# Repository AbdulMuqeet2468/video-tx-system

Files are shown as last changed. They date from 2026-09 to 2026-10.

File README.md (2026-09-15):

# video-tx-system

Under progress...

## Trail 1
Planned to use TPS54560BQDDARQ1 IC from Texas Instruments; 50V input and 5V 6A output. 
- Footprint was too big
- Inductor (15uH 11A) had bigger footprint and not available

## Trail 2
Using LM76003RNPR with lesser eficiency and better footprint. 
- Completed simulation
- Created symbols and footprints for missing components
- completed schematic

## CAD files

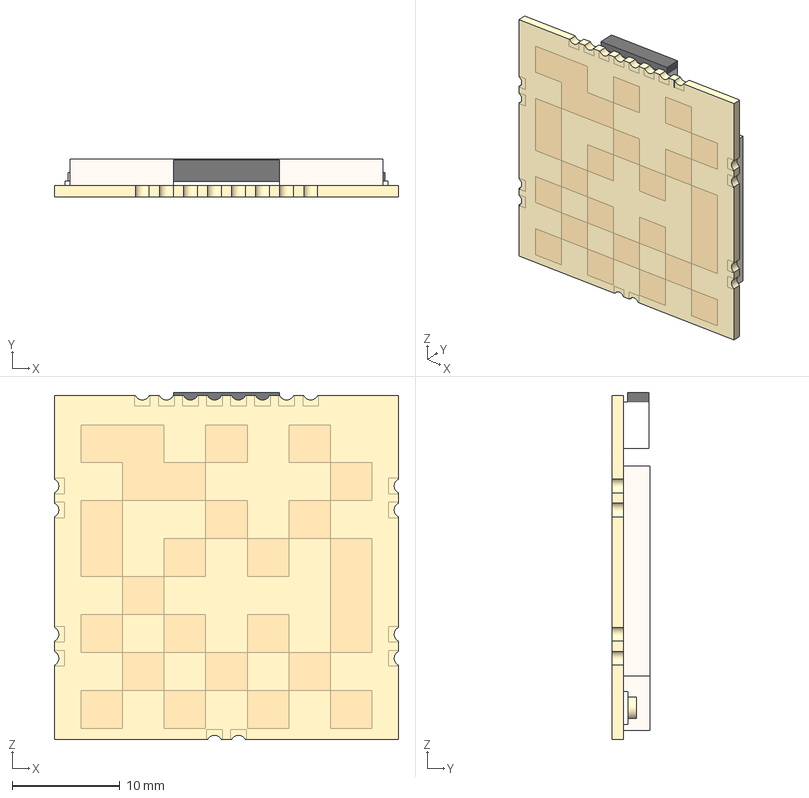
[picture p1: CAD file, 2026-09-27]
3D CAD Files/BL-M8812EU2 Long Range Wifi Module.stp
32.0 x 3.53 x 32.3 mm

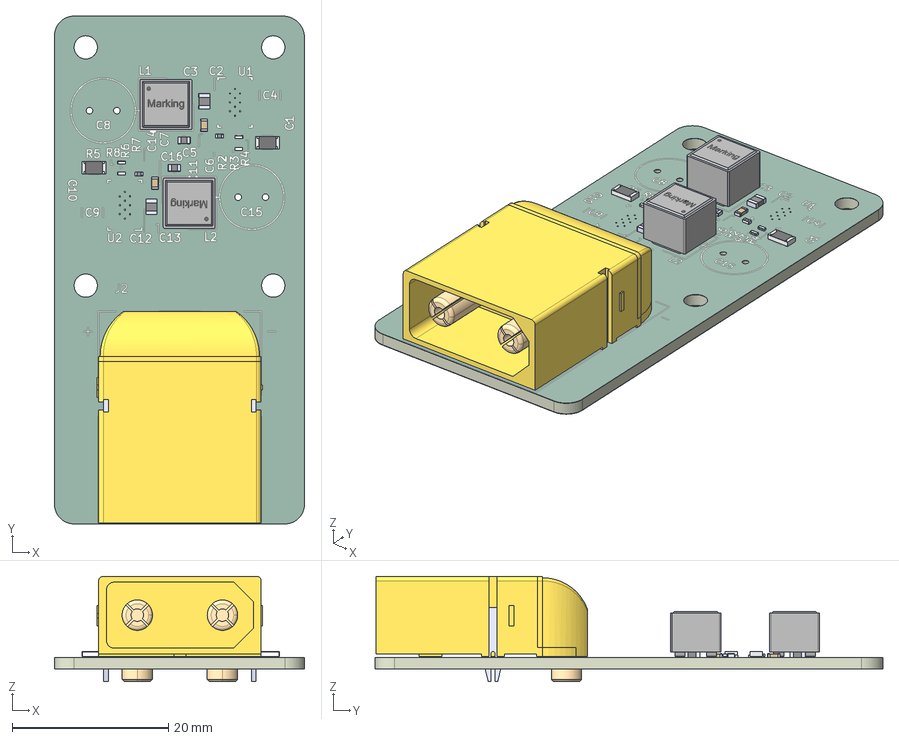
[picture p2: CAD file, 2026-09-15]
KiCAD Files/VTX.step
32.0 x 65.0 x 13.5 mm
RT1206BRD07120RL x 2
CC0603ZRY5V8BB105 x 2
AC0805KKX7R0BB104 x 2
RE0402FRE07100KL x 2
XT90PW-M
SR0402JR-7W10RL x 4
CL10A104KA8NNNC x 2
L_Wurth_WE-XHMI_6060 x 2
VTXED8C_silkscreen
VTXED8C_soldermask x 2
VTXED8C_PCB

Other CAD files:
3D CAD Files/BL-M8812EU2 Long Range Wifi Module.SLDPRT

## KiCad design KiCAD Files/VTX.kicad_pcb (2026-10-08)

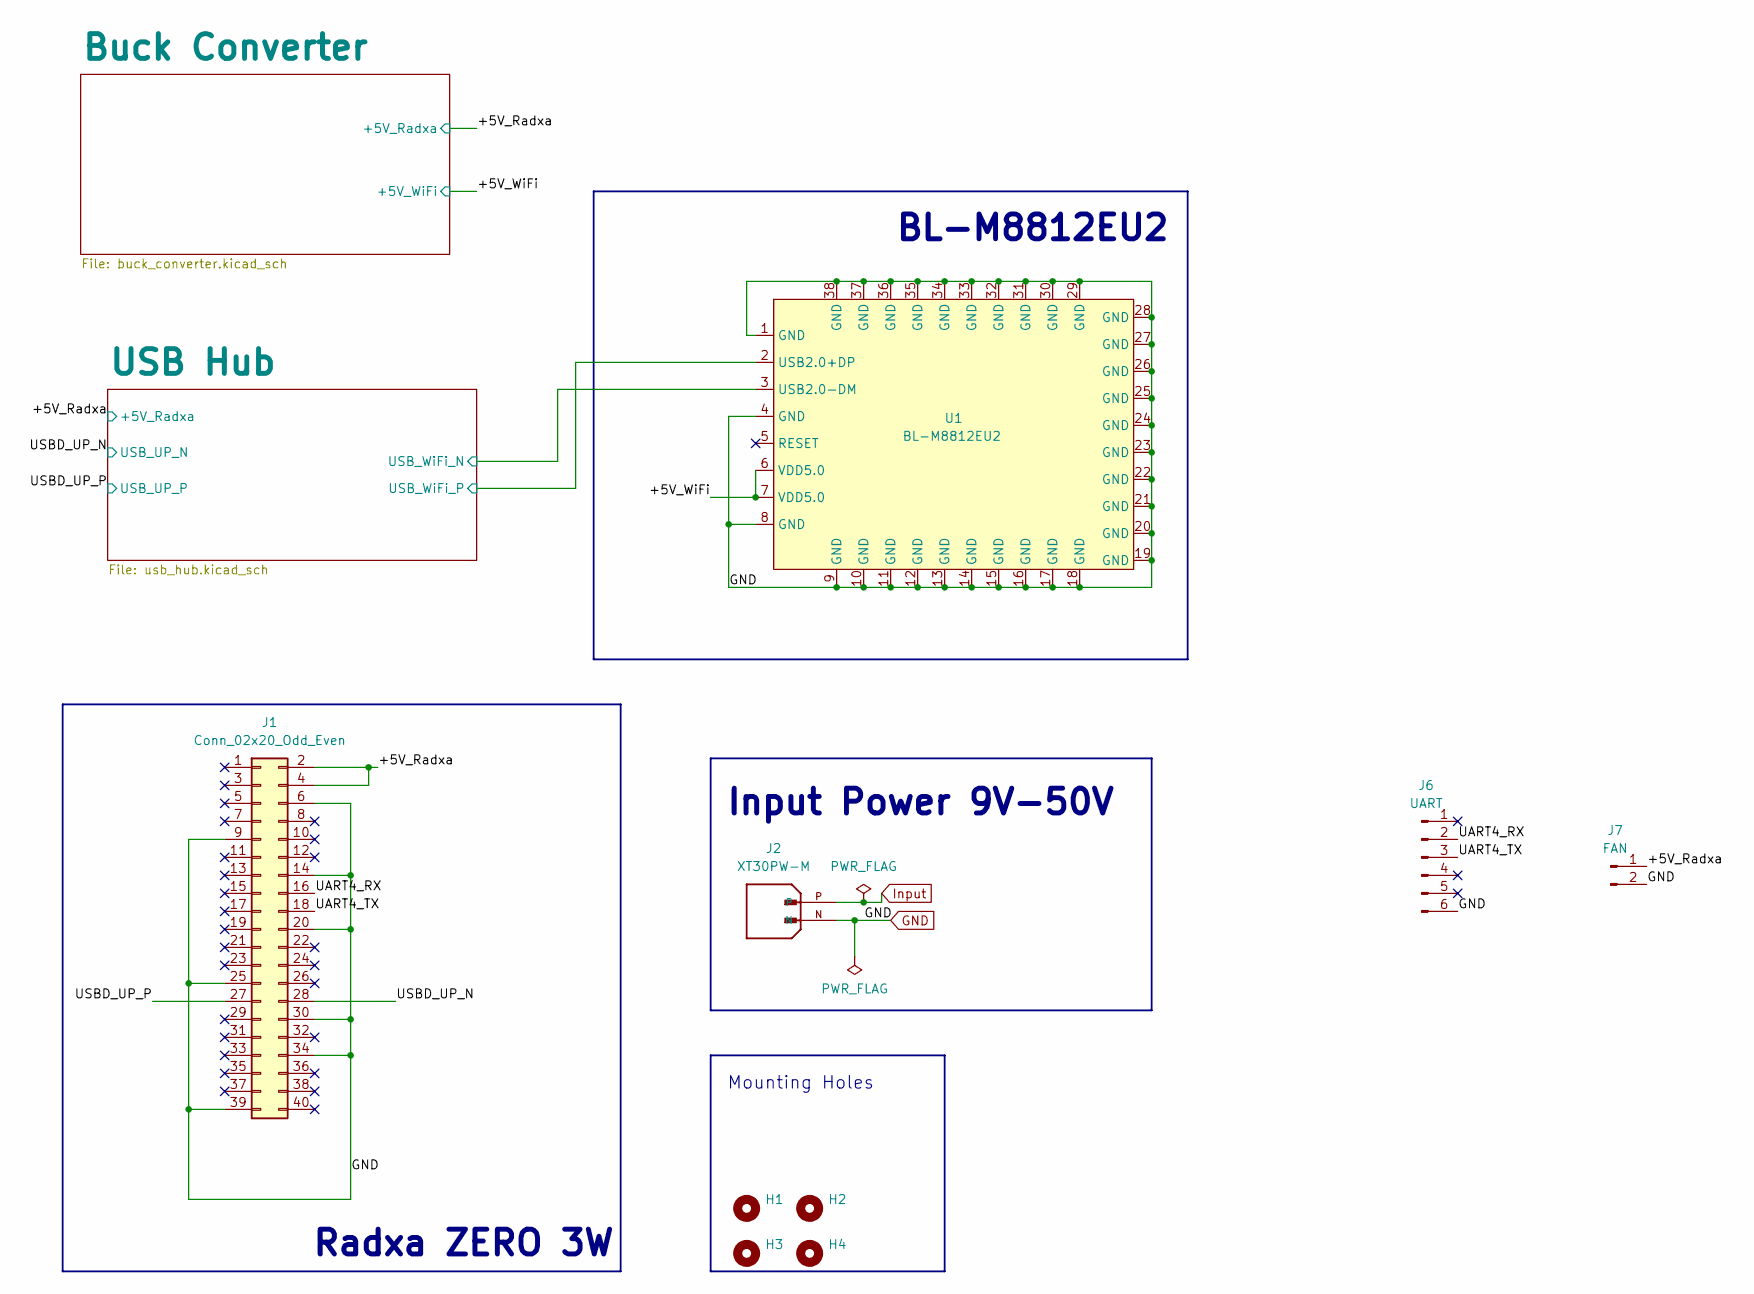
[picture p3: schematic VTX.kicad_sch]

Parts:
H1, H2, H3, H4: MountingHole; MountingHole_3mm
J1: Conn_02x20_Odd_Even; PinHeader_2x20_P2.54mm_Vertical
J2: XT30PW-M; AMASS_XT30PW-M; PARTREV 1.2
J6: UART; JST_GH_SM06B-GHS-TB_1x06-1MP_P1.25mm_Horizontal
J7: FAN; JST_GH_SM02B-GHS-TB_1x02-1MP_P1.25mm_Horizontal
U1: BL-M8812EU2

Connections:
+5V_Radxa: J1.2, J1.4, J7.1; also elsewhere on the board
+5V_WiFi: U1.6 (VDD5.0), U1.7 (VDD5.0); also elsewhere on the board
/UART4_RX: J1.16, J6.2
/UART4_TX: J1.18, J6.3
/USB Hub/USB_WiFi_N: U1.3 (USB2.0-DM); also elsewhere on the board
/USB Hub/USB_WiFi_P: U1.2 (USB2.0+DP); also elsewhere on the board
/USBD_UP_N: J1.28; also elsewhere on the board
/USBD_UP_P: J1.27; also elsewhere on the board
GND: J1.6, J1.9, J1.14, J1.20, J1.25, J1.30, J1.34, J1.39, J2.N, J6.6, J7.2, U1.1 (GND), U1.4 (GND), U1.8 (GND), U1.9 (GND), U1.10 (GND), U1.11 (GND), U1.12 (GND), U1.13 (GND), U1.14 (GND), U1.15 (GND), U1.16 (GND), U1.17 (GND), U1.18 (GND), U1.19 (GND), U1.20 (GND), U1.21 (GND), U1.22 (GND), U1.23 (GND), U1.24 (GND), U1.25 (GND), U1.26 (GND), U1.27 (GND), U1.28 (GND), U1.29 (GND), U1.30 (GND), U1.31 (GND), U1.32 (GND), U1.33 (GND), U1.34 (GND), U1.35 (GND), U1.36 (GND), U1.37 (GND), U1.38 (GND); also elsewhere on the board
Input: J2.P; also elsewhere on the board

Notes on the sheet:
BL-M8812EU2
Mounting Holes
Radxa ZERO 3W
Input Power 9V-50V

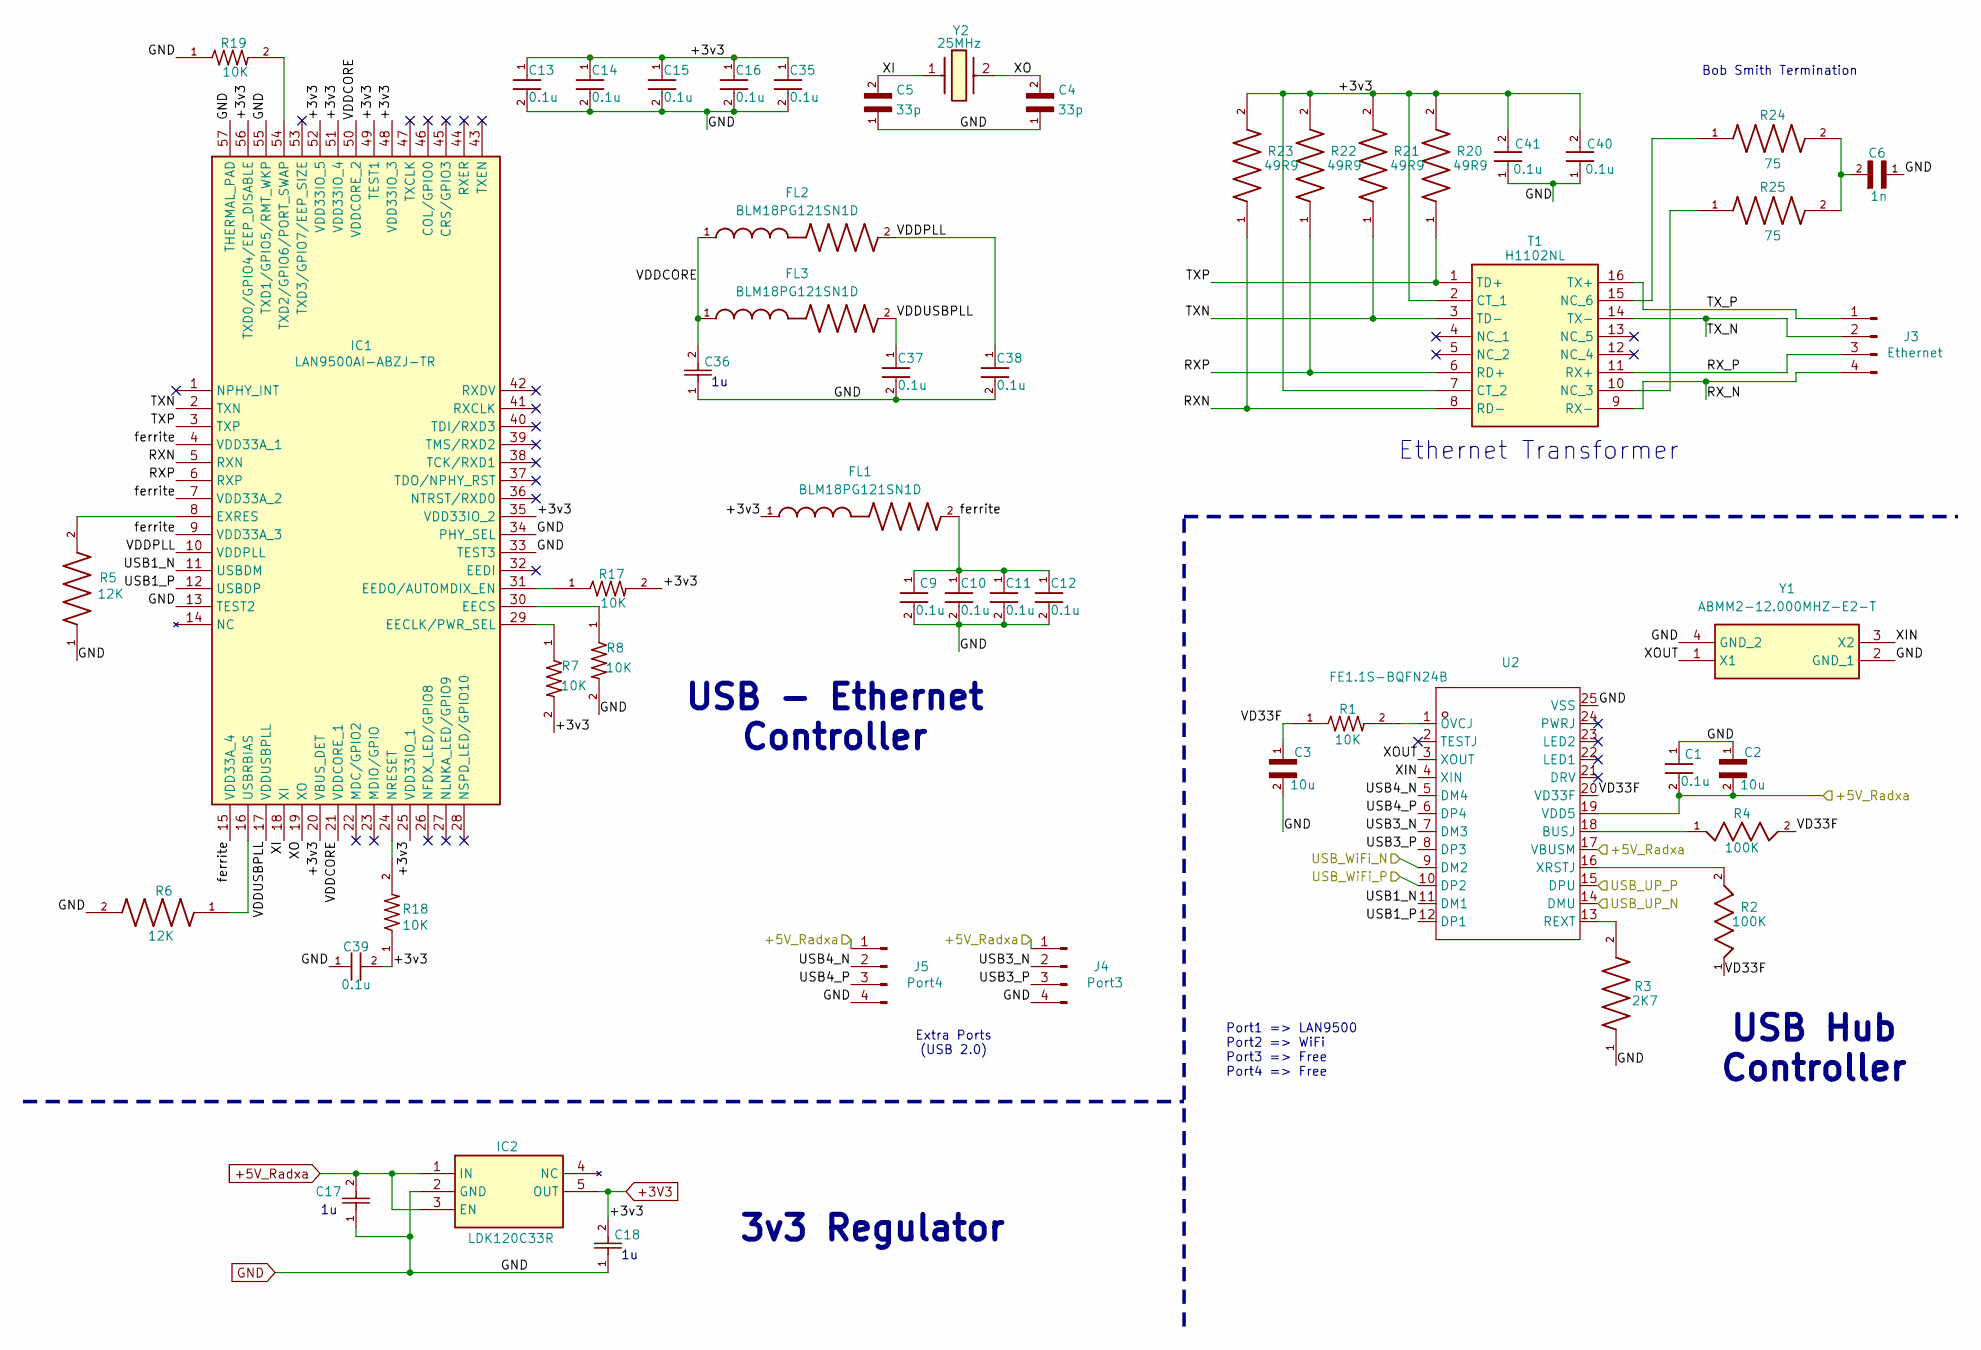
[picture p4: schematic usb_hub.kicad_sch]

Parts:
C1, C9, C10, C11, C12, C13, C14, C15, C16, C35, C37, C38, C39, C40, C41: 0.1u; 100nF0603
C2, C3: 10u; CL10A106KQ8NNNC
C4, C5: 33p; TCC0402COG330J500AT; PARTREV 2015-02-10
C6: 1n; C1206C102JGRACTU
C17, C18: 1uF; CC0805KKX7R6BB225; VOLTAGERATING 10V; TOLERANCE ±10%; MPN CC0805KKX7R6BB225
C36: 1uF; C0805X474K101T; VOLTAGERATING 10V; TOLERANCE ±10%; MPN CC0805KKX7R6BB225
FL1, FL2, FL3: BLM18PG121SN1D
IC1: LAN9500AI-ABZJ-TR; Manufacturer_Part_Number LAN9500AI-ABZJ-TR
IC2: LDK120C33R; Manufacturer_Part_Number LDK120C33R
J3: Ethernet; JST_GH_SM04B-GHS-TB_1x04-1MP_P1.25mm_Horizontal
J4: Port3; JST_GH_SM04B-GHS-TB_1x04-1MP_P1.25mm_Horizontal
J5: Port4; JST_GH_SM04B-GHS-TB_1x04-1MP_P1.25mm_Horizontal
R1, R7, R8, R17, R18, R19: 10K; RC0603JR-0710KL; DigiKey_Part_Number 311-10KGRCT-ND
R2, R4: 100K; RC0402FR-07100KL
R3: 2K7; RC0805FR-072K7L
R5, R6: 12K; RC0805FR-0712KL
R20, R21, R22, R23: 49R9; RC0805FR-0749R9L
R24, R25: 75; RC0805FR-0775RL
T1: H1102NL; Manufacturer_Part_Number H1102NL
U2: FE1.1S-BQFN24B; VOLTAGE - SUPPLY 4.5V~5.5V；3V~3.6V; MANUFACTURERPART FE1.1S-BQFN24B; LCSC PART NAME USB 2.0 4-端口集线器控制器
Y1: ABMM2-12.000MHZ-E2-T; ABMM2-12MHz; Manufacturer_Part_Number ABMM2-12.000MHZ-E2-T
Y2: 25MHz; ABM7-25MHz; Manufacturer_Part_Number ABM7-25.000MHZ-D2Y-T

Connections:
+3V3: C13.1, C14.1, C15.1, C16.1, C18.2, C35.1, C39.2, C40.2, C41.2, FL1.1, IC1.20 (VBUS_DET), IC1.25 (VDD33IO_1), IC1.35 (VDD33IO_2), IC1.48 (VDD33IO_3), IC1.49 (TEST1), IC1.51 (VDD33IO_4), IC1.52 (VDD33IO_5), IC1.56 (TXD0/GPIO4/EEP_DISABLE), IC2.5 (OUT), R7.2, R17.2, R18.1, R20.2, R21.2, R22.2, R23.2, T1.2 (CT_1), T1.7 (CT_2)
+5V_Radxa: C1.2, C2.2, C17.2, IC2.1 (IN), IC2.3 (EN), J4.1, J5.1, U2.17 (VBUSM), U2.19 (VDD5); also elsewhere on the board
/USB Hub/RXN: IC1.5 (RXN), R23.1, T1.8 (RD-)
/USB Hub/RXP: IC1.6 (RXP), R22.1, T1.6 (RD+)
/USB Hub/RX_N: J3.4, T1.9 (RX-)
/USB Hub/RX_P: J3.3, T1.11 (RX+)
/USB Hub/TXN: IC1.2 (TXN), R21.1, T1.3 (TD-)
/USB Hub/TXP: IC1.3 (TXP), R20.1, T1.1 (TD+)
/USB Hub/TX_N: J3.2, T1.14 (TX-)
/USB Hub/TX_P: J3.1, T1.16 (TX+)
/USB Hub/USB1_N: IC1.11 (USBDM), U2.11 (DM1)
/USB Hub/USB1_P: IC1.12 (USBDP), U2.12 (DP1)
/USB Hub/USB3_N: J4.2, U2.7 (DM3)
/USB Hub/USB3_P: J4.3, U2.8 (DP3)
/USB Hub/USB4_N: J5.2, U2.5 (DM4)
/USB Hub/USB4_P: J5.3, U2.6 (DP4)
/USB Hub/USB_WiFi_N: U2.9 (DM2); also elsewhere on the board
/USB Hub/USB_WiFi_P: U2.10 (DP2); also elsewhere on the board
/USB Hub/VD33F: C3.1, R1.1, R2.1, R4.2, U2.20 (VD33F)
/USB Hub/VDDCORE: C36.2, FL2.1, FL3.1, IC1.21 (VDDCORE_1), IC1.50 (VDDCORE_2)
/USB Hub/VDDPLL: C38.1, FL2.2, IC1.10 (VDDPLL)
/USB Hub/VDDUSBPLL: C37.1, FL3.2, IC1.17 (VDDUSBPLL)
/USB Hub/XI: C5.2, IC1.18 (XI), Y2.1
/USB Hub/XIN: U2.4 (XIN), Y1.3 (X2)
/USB Hub/XO: C4.2, IC1.19 (XO), Y2.2
/USB Hub/XOUT: U2.3 (XOUT), Y1.1 (X1)
/USB Hub/ferrite: C9.1, C10.1, C11.1, C12.1, FL1.2, IC1.4 (VDD33A_1), IC1.7 (VDD33A_2), IC1.9 (VDD33A_3), IC1.15 (VDD33A_4)
/USBD_UP_N: U2.14 (DMU); also elsewhere on the board
/USBD_UP_P: U2.15 (DPU); also elsewhere on the board
GND: C1.1, C2.1, C3.2, C4.1, C5.1, C6.1, C9.2, C10.2, C11.2, C12.2, C13.2, C14.2, C15.2, C16.2, C17.1, C18.1, C35.2, C36.1, C37.2, C38.2, C39.1, C40.1, C41.1, IC1.13 (TEST2), IC1.33 (TEST3), IC1.34 (PHY_SEL), IC1.55 (TXD1/GPIO5/RMT_WKP), IC1.57 (THERMAL_PAD), IC2.2 (GND), J4.4, J5.4, R3.1, R5.1, R6.2, R8.2, R19.1, U2.25 (VSS), Y1.2 (GND_1), Y1.4 (GND_2); also elsewhere on the board
unnamed: C6.2, R24.2, R25.2
unnamed: IC1.29 (EECLK/PWR_SEL), R7.1
unnamed: IC1.30 (EECS), R8.1
unnamed: IC1.31 (EEDO/AUTOMDIX_EN), R17.1
unnamed: IC1.8 (EXRES), R5.2
unnamed: IC1.24 (NRESET), R18.2
unnamed: IC1.54 (TXD2/GPIO6/PORT_SWAP), R19.2
unnamed: IC1.16 (USBRBIAS), R6.1
unnamed: R25.1, T1.10 (NC_3)
unnamed: R24.1, T1.15 (NC_6)
unnamed: R4.1, U2.18 (BUSJ)
unnamed: R1.2, U2.1 (OVCJ)
unnamed: R3.2, U2.13 (REXT)
unnamed: R2.2, U2.16 (XRSTJ)

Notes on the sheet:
Extra Ports (USB 2.0)
Ethernet Transformer
Bob Smith Termination
Port1 => LAN9500 Port2 => WiFi Port3 => Free Port4 => Free
3v3 Regulator
USB Hub Controller
USB - Ethernet Controller

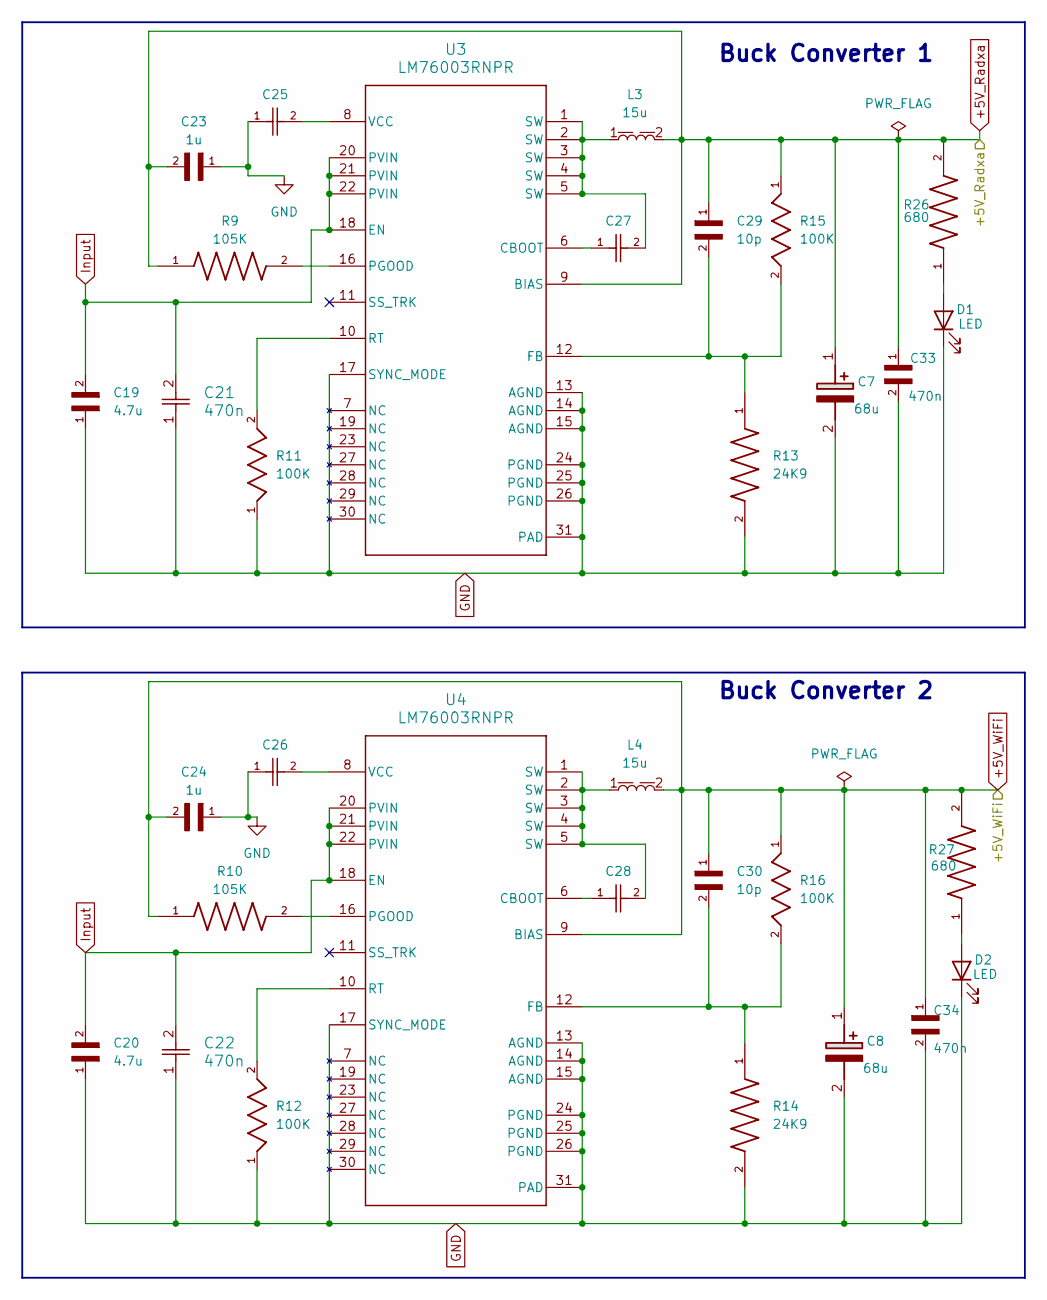
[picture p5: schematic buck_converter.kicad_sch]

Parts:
C7, C8: 68u; 10SVPC68MV; Manufacturer_Part_Number 10SVPC68MV
C19, C20: 4.7u; CS3225X7R475K101NRK
C21, C22: 470n; C0805X474K101T
C23, C24: 1u; CC0603KRX5R6BB105
C25, C26: 2.2uF; CC0805KKX7R6BB225; VOLTAGERATING 10V; TOLERANCE ±10%; MPN CC0805KKX7R6BB225
C27, C28: 2.2uF; CS1005X7R474K6R3NR; VOLTAGERATING 10V; TOLERANCE ±10%; MPN CC0805KKX7R6BB225
C29, C30: 10p; 10pF16V
C33, C34: 470n; CL10A474KB8NNNC
D1, D2: LED; RC0805FR-07680RL
L3, L4: 6060_78439346150; L78439346150; Part Number 78439346150
R9, R10: 105K; RC1206FR-07105KL
R11, R12, R15, R16: 100K; RC0402FR-07100KL
R13, R14: 24K9; AC0402FR-0724K9L
R26, R27: 680; RC0805FR-07680RL
U3, U4: LM76003RNPR

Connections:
+5V_Radxa: C7.1 (+), C23.2, C29.1, C33.1, L3.2, R9.1, R15.1, R26.2, U3.9 (BIAS); also elsewhere on the board
+5V_WiFi: C8.1 (+), C24.2, C30.1, C34.1, L4.2, R10.1, R16.1, R27.2, U4.9 (BIAS); also elsewhere on the board
GND: C7.2 (-), C8.2 (-), C19.1, C20.1, C21.1, C22.1, C23.1, C24.1, C25.1, C26.1, C33.2, C34.2, D1.1 (K), D2.1 (K), R11.1, R12.1, R13.2, R14.2, U3.13 (AGND), U3.14 (AGND), U3.15 (AGND), U3.17 (SYNC_MODE), U3.24 (PGND), U3.25 (PGND), U3.26 (PGND), U3.31 (PAD), U4.13 (AGND), U4.14 (AGND), U4.15 (AGND), U4.17 (SYNC_MODE), U4.24 (PGND), U4.25 (PGND), U4.26 (PGND), U4.31 (PAD); also elsewhere on the board
Input: C19.2, C20.2, C21.2, C22.2, U3.18 (EN), U3.20 (PVIN), U3.21 (PVIN), U3.22 (PVIN), U4.18 (EN), U4.20 (PVIN), U4.21 (PVIN), U4.22 (PVIN); also elsewhere on the board
unnamed: C27.2, L3.1, U3.1 (SW), U3.2 (SW), U3.3 (SW), U3.4 (SW), U3.5 (SW)
unnamed: C28.2, L4.1, U4.1 (SW), U4.2 (SW), U4.3 (SW), U4.4 (SW), U4.5 (SW)
unnamed: D1.2 (A), R26.1
unnamed: D2.2 (A), R27.1
unnamed: C27.1, U3.6 (CBOOT)
unnamed: C29.2, R13.1, R15.2, U3.12 (FB)
unnamed: R9.2, U3.16 (PGOOD)
unnamed: R11.2, U3.10 (RT)
unnamed: C25.2, U3.8 (VCC)
unnamed: C28.1, U4.6 (CBOOT)
unnamed: C30.2, R14.1, R16.2, U4.12 (FB)
unnamed: R10.2, U4.16 (PGOOD)
unnamed: R12.2, U4.10 (RT)
unnamed: C26.2, U4.8 (VCC)

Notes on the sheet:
Buck Converter 1
Buck Converter 2

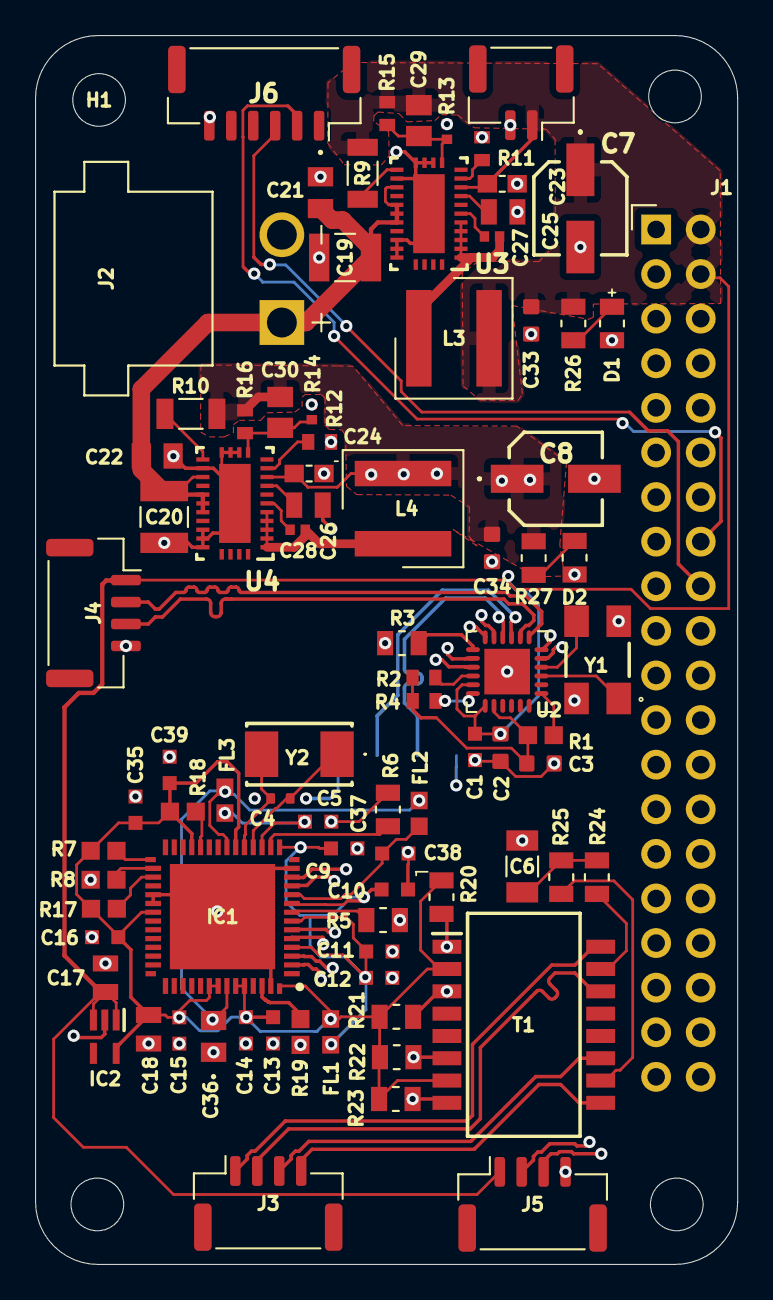
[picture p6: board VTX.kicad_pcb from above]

Board: 4 copper layers, 40.0 x 70.0 mm, 91 parts (0 on the bottom side), 62 nets.

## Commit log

2026-09-15 Radxa Part file
    [BL-M8812EU2 Long Range Wifi Module.SLDPRT]
2026-09-19 USB Controller Ready
    [VTX.kicad_pcb, VTX.kicad_sch, buck_converter.kicad_sch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]
2026-09-27 Ethernet routing pending
    [BL-M8812EU2 Long Range Wifi Module.stp, VTX.kicad_pcb, VTX.kicad_sch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]
2026-10-02 Final Push
    [VTX.kicad_pcb]
2026-10-08 push after error check
    [VTX.kicad_pcb]
